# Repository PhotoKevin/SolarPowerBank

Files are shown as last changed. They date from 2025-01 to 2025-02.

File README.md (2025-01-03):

# SolarPowerBank
Solar charged power bank

This is a replacement for one I had cobbled together using some ready made boards. The redesign is intended to
address two major areas:

* Airline compatible. Commercial units tend to be all-in-one. You can't separate the battery pack from the solar
panel. This is a problem since you can't put LIon batteries in checked luggage. This unit is designed to be
separate from the panel.
* Fast charge. The old one could only do 500mA charging.  The idea is to keep a battery charging all day and
be able to quick charge a phone.
* Designed to go in a box. If you build something from pre-made boards such as those from AdaFruit, the connectors
are all on the board. This is set up to use "panel mount" connectors.

## Hardware design
The design works around two integrated circuits. A Texas Instruments BQ25185 and an iSmartWare SW2303.

### BQ25185
The TI BQ25185 is a multi-chemistry battery charging controller. The key feature for this application is that it's solar compatible. Solar panels will shut down if you try to draw too much current from them. This can lead to an infinite start/stop cycle which is inefficient and will reduce battery life. [Datasheet](http://www.ti.com/lit/ds/symlink/bq51050b.pdf)

### SW2303
The iSmartWare SW2303 is a fast USB charging module. [Datasheet](http://www.ismartware.cn/upload/goods/20220721/202207211507542921.pdf)

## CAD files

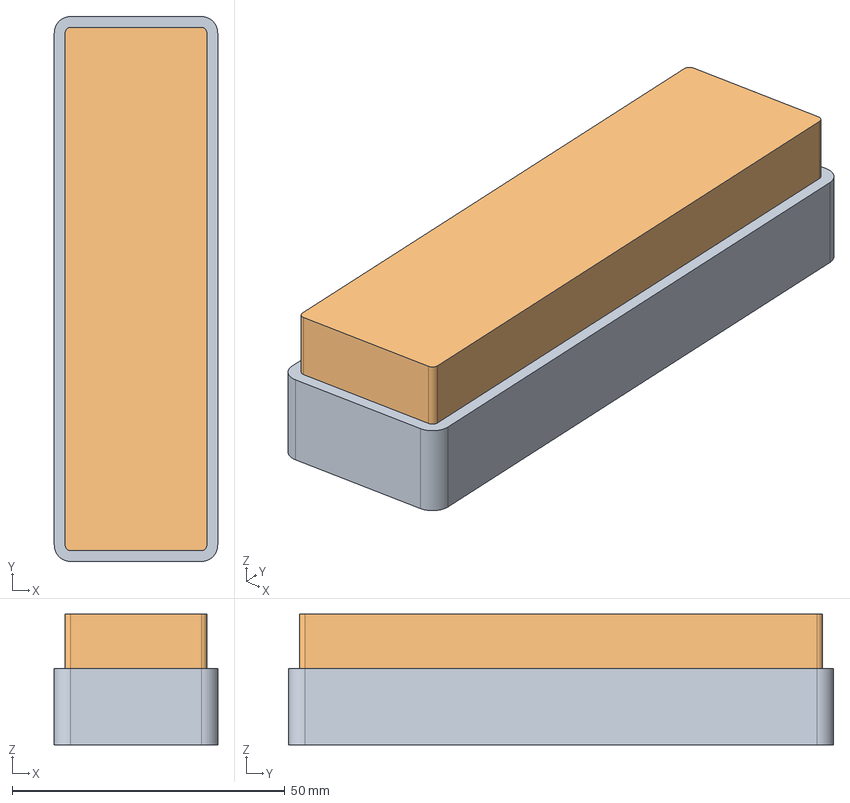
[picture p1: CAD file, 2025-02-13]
FreeCAD/ProjectBoxSolar.FCStd
30.0 x 100.0 x 24.0 mm
Bottom

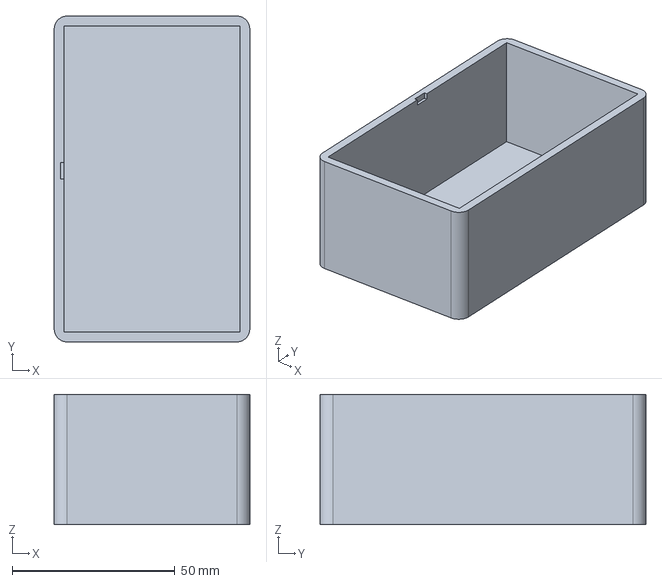
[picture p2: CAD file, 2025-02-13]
FreeCAD/RoundTwo.FCStd
60.0 x 100.0 x 40.0 mm

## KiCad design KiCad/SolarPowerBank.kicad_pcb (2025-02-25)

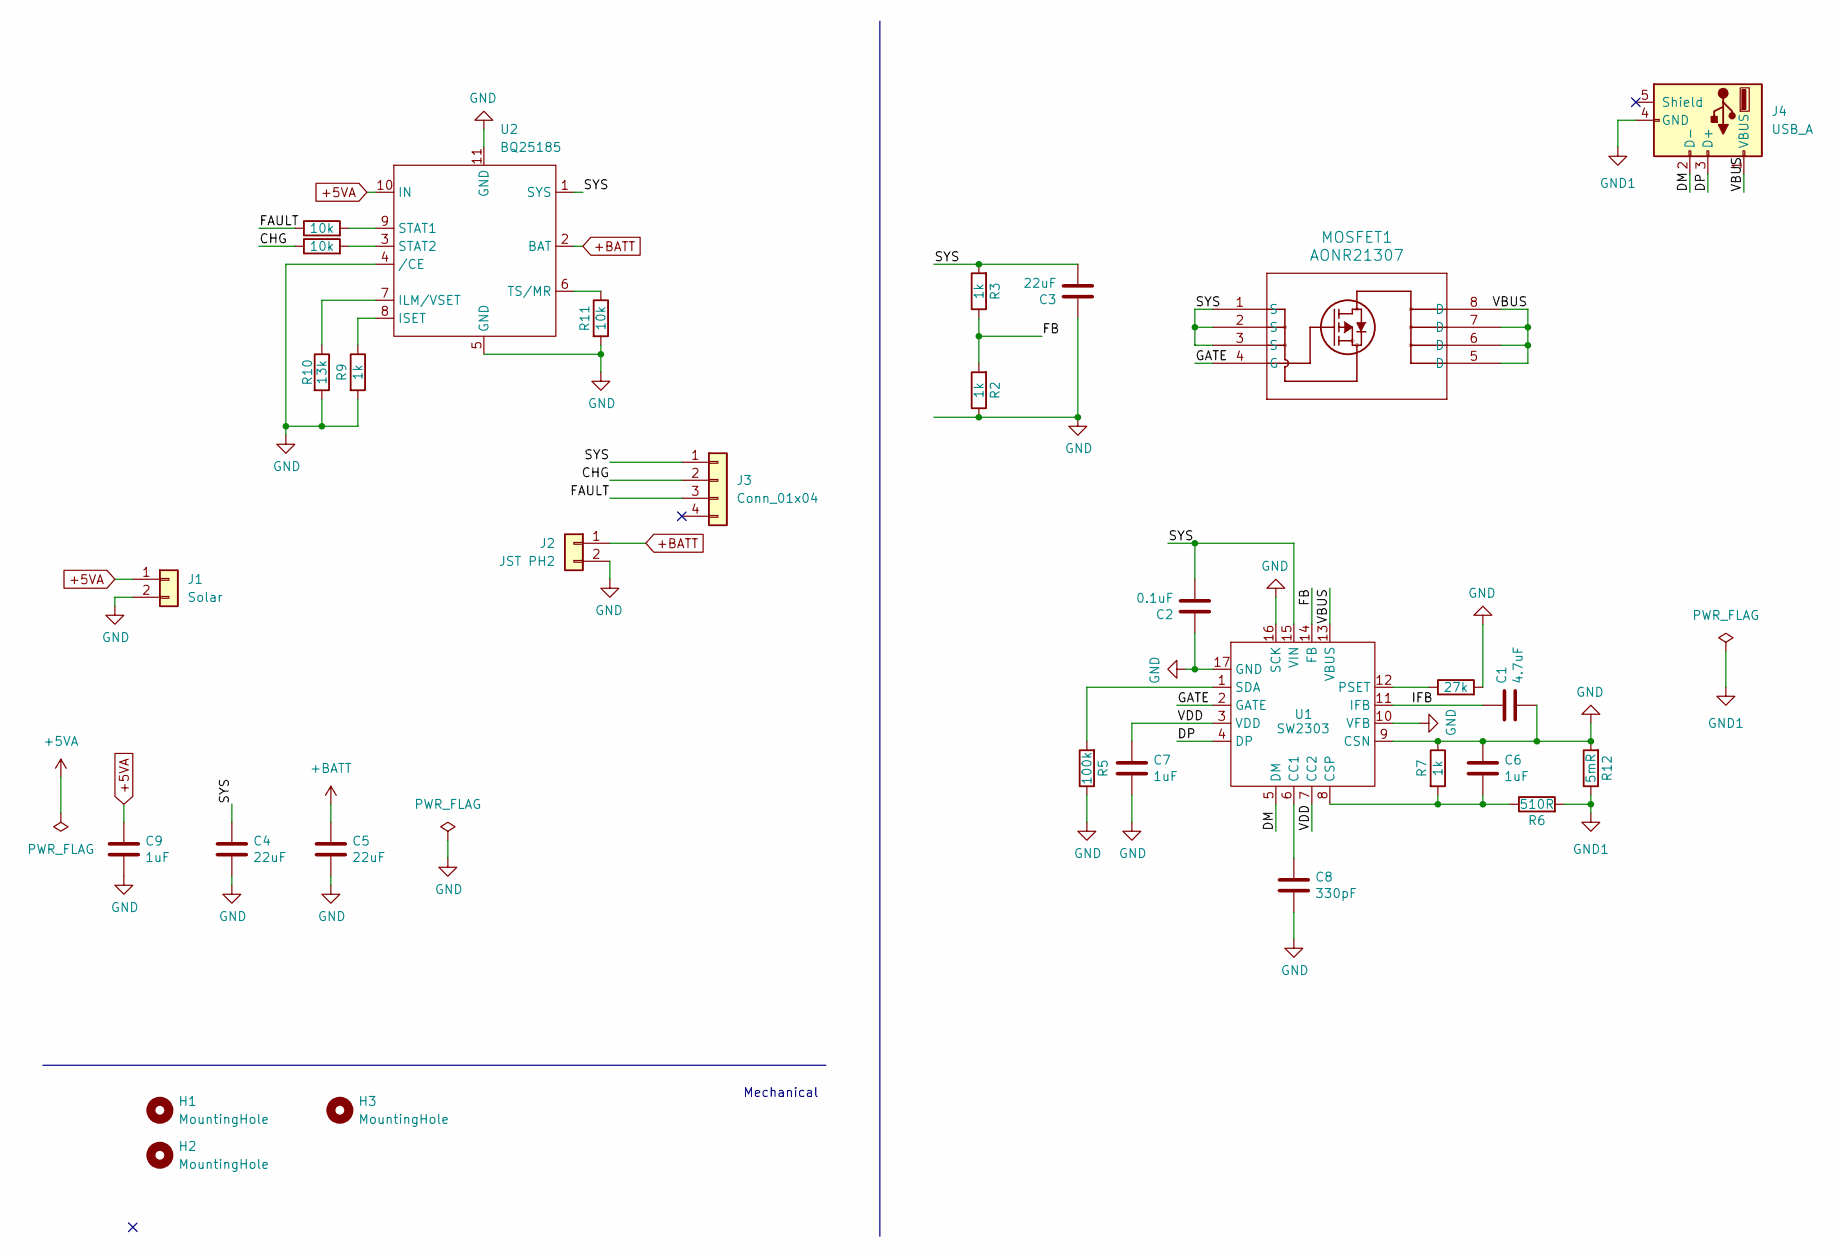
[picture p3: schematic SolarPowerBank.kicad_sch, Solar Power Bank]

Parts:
C1: 4.7uF; C_1206_3216Metric_Pad1.33x1.80mm_HandSolder
C2: 0.1uF; C_1206_3216Metric_Pad1.33x1.80mm_HandSolder
C3, C4, C5: 22uF; C_1206_3216Metric_Pad1.33x1.80mm_HandSolder
C6, C7, C9: 1uF; C_1206_3216Metric_Pad1.33x1.80mm_HandSolder
C8: 330pF; C_1206_3216Metric_Pad1.33x1.80mm_HandSolder
H1, H2, H3: MountingHole; MountingHole_3.5mm
J1: Solar; PinHeader_1x02_P2.54mm_Vertical
J2: JST PH2; JST_PH_S2B-PH-K_1x02_P2.00mm_Horizontal
J3: Conn_01x04; PinHeader_2x02_P2.54mm_Vertical
J4: USB_A; PinHeader_1x05_P2.54mm_Vertical
MOSFET1: AONR21307; DFN3x3A_8L_EP1_P
R1: 27k; R_1206_3216Metric_Pad1.30x1.75mm_HandSolder
R2, R3, R7, R9: 1k; R_1206_3216Metric_Pad1.30x1.75mm_HandSolder
R4, R8, R11: 10k; R_1206_3216Metric_Pad1.30x1.75mm_HandSolder
R5: 100k; R_1206_3216Metric_Pad1.30x1.75mm_HandSolder
R6: 510R; R_1206_3216Metric_Pad1.30x1.75mm_HandSolder
R10: 13k; R_1206_3216Metric_Pad1.30x1.75mm_HandSolder
R12: 5mR; R_1206_3216Metric_Pad1.30x1.75mm_HandSolder
U1: SW2303; QFN-16-1EP_4x4mm_P0.65mm_EP2.15x2.15mm_ThermalVias-HandSold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
U2: BQ25185; WSON-10-1EP_2.2x2.0mm_P0.4_ThermalVias-HandSolder

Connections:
+5VA: C9.1, J1.1, U2.10 (IN)
+BATT: C5.1, J2.1, U2.2 (BAT)
/CHG: J3.2, R4.1
/DM: J4.2 (D-), U1.5 (DM)
/DP: J4.3 (D+), U1.4 (DP)
/FAULT: J3.3, R8.1
/FB: R2.2, R3.1, U1.14 (FB)
/GATE: MOSFET1.4 (G), U1.2 (GATE)
/IFB: C1.1, U1.11 (IFB)
/SYS: C2.2, C3.2, C4.1, J3.1, MOSFET1.1 (S), MOSFET1.2 (S), MOSFET1.3 (S), R3.2, U1.15 (VIN), U2.1 (SYS)
/VBUS: J4.1 (VBUS), MOSFET1.5 (D), MOSFET1.6 (D), MOSFET1.7 (D), MOSFET1.8 (D), U1.13 (VBUS)
/VDD: C7.1, U1.3 (VDD), U1.7 (CC2)
GND: C1.2, C2.1, C3.1, C4.2, C5.2, C6.1, C7.2, C8.2, C9.2, J1.2, J2.2, R1.2, R2.1, R5.1, R7.1, R9.2, R10.2, R11.2, R12.2, U1.9 (CSN), U1.10 (VFB), U1.16 (SCK), U1.17 (GND), U2.4 (/CE), U2.5 (GND), U2.11 (GND)
GND1: J4.4 (GND), R6.2, R12.1
unnamed: C8.1, U1.6 (CC1)
unnamed: C6.2, R6.1, R7.2, U1.8 (CSP)
unnamed: R1.1, U1.12 (PSET)
unnamed: R5.2, U1.1 (SDA)
unnamed: R10.1, U2.7 (ILM/VSET)
unnamed: R9.1, U2.8 (ISET)
unnamed: R8.2, U2.9 (STAT1)
unnamed: R4.2, U2.3 (STAT2)
unnamed: R11.1, U2.6 (TS/MR)

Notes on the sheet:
Mechanical

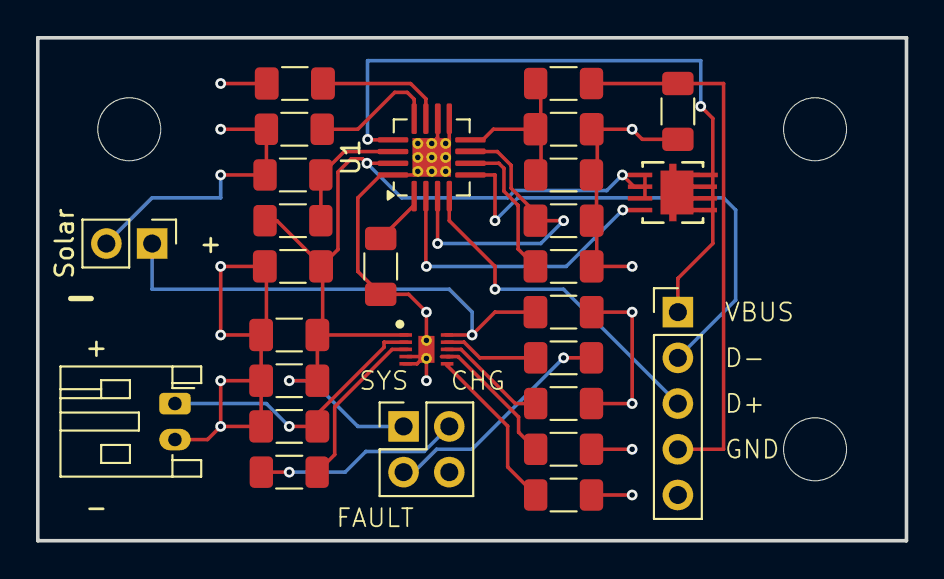
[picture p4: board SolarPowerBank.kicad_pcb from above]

Board: 2 copper layers, 48.3 x 27.9 mm, 31 parts (0 on the bottom side), 23 nets.

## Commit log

2025-01-03 Initial PCB version. Untested at time of commit.
    [SolarPowerBank.kicad_pcb, SolarPowerBank.kicad_sch]
2025-01-26 Move KiCad files to their own directory.
    [SolarPowerBank.kicad_pcb, SolarPowerBank.kicad_sch]
2025-02-13 Changed footprints to allow for easier hand soldering
    [ProjectBoxSolar.FCStd, RoundTwo.FCStd, SolarPowerBank.kicad_pcb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]
2025-02-25 Update to KiCad 9.0
    [SolarPowerBank.kicad_pcb, SolarPowerBank.kicad_sch]
